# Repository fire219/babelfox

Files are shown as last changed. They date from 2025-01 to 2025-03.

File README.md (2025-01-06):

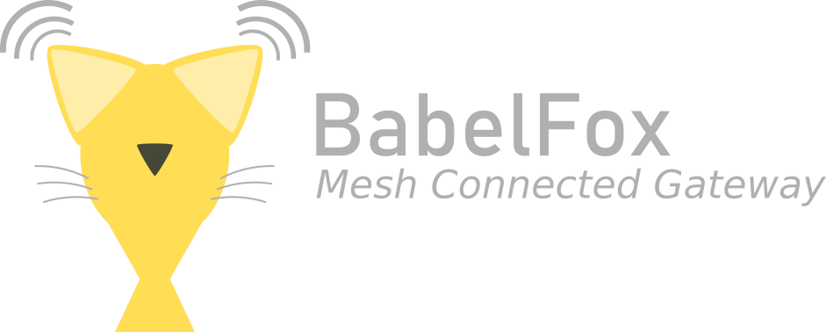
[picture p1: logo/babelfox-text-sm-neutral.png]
BabelFox logo

**NOTE: This project is not quite ready for prime time. Everything could be subject to change; build at your own risk. More documentation will come on full release.**

## What is this?
**BabelFox** is a project to create an energy efficient yet high performance Meshtastic "remote gateway node" -- one which not only has a wide TX/RX range on the mesh, but also can bridge the gap to other communication protocols, *without the need for any additional equipment*. It is equipped with a LoRA module based on the **Semtech LR1121** chip, which not only provides better RX performance than the standard SX1262 used by most Meshtastic hardware, but also includes 2.4GHz LoRA capability. It is also equipped with a **SIMCom SIM7022** LTE modem, which provides low power NB-IoT internet connectivity, with global cellular band support.

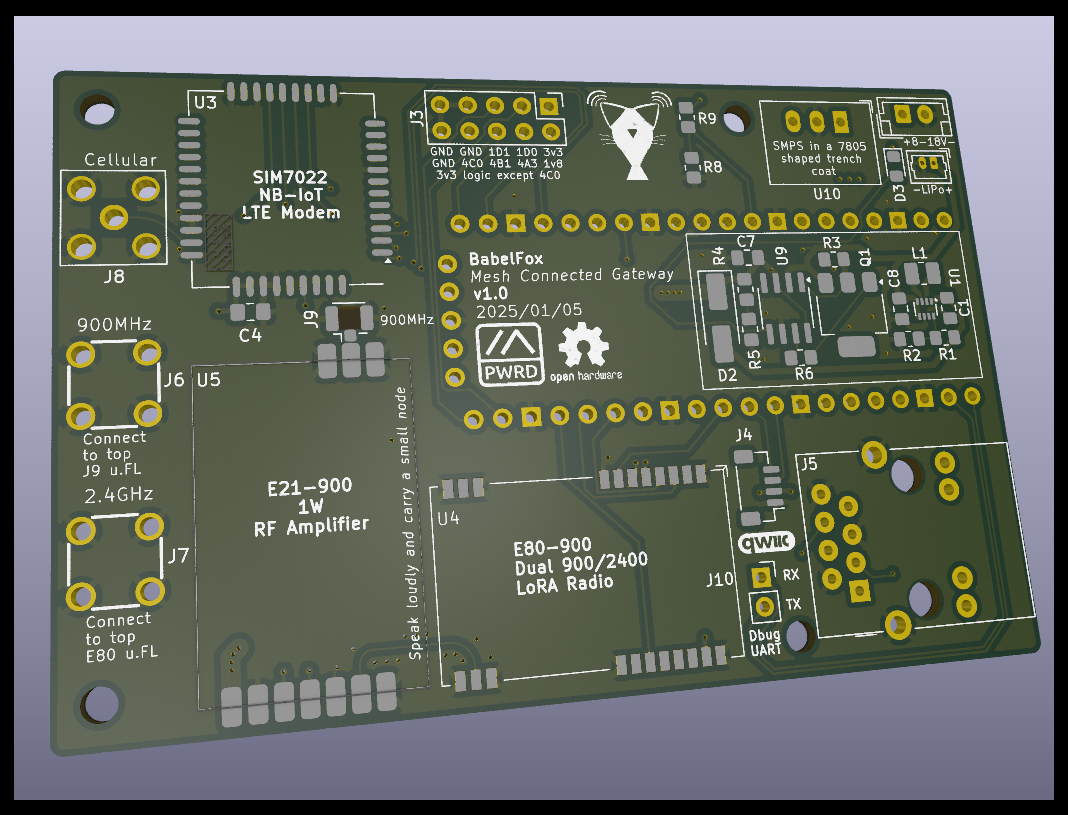
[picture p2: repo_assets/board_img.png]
BabelFox board view


## Specifications
**Form factor:** RPi compatible (85x56mm, with 58x49mm spaced mounting holes)

**Main Processor:** Luckfox Pico (based on Rockchip RV1103)

**LoRA Radio:** EByte E80-900 (based on Semtech LR1121)

**900MHz Amplifier:** EByte E21-900 1W PA/LNA

**Cell Radio:** SIMCom SIM7022

**Max LoRA TX Power:** 30dBm @ 900MHz, 13dBm @ 2.4GHz

**Power Source:** USB-C (5V only), 3.7V LiPo, 8-18V VDC

**Power Consumption:** ~5W peak, <3W nominal

## License

**BabelFox** is licensed under the CERN OHL v2 Strongly Reciprocal license. See the *LICENSE* file for more information.

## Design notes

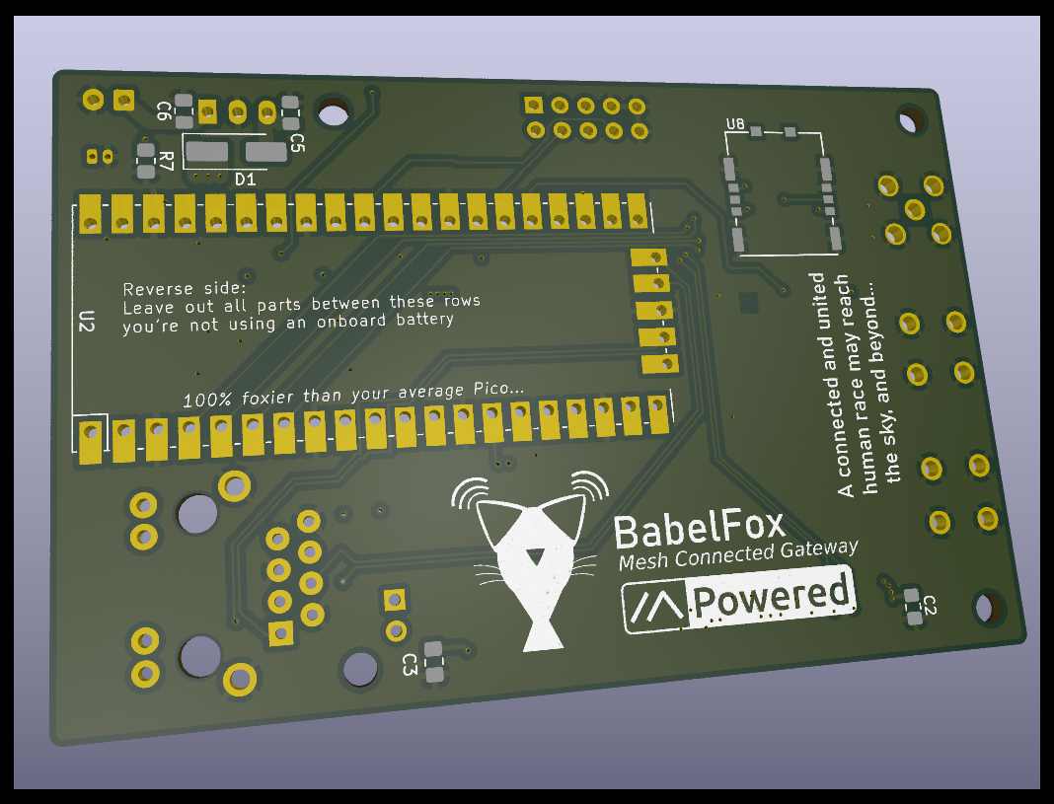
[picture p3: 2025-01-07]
repo_assets/board_img2.png

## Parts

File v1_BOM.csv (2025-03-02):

Reference | Value | Footprint | Qty | Notes
C1 | 100uF | Capacitor_SMD:C_0805_2012Metric_Pad1.18x1.45mm_HandSolder | 1 | 6V, DNP if no battery circuit
C2,C3,C4,C5,C6,C8 | 10uF | Capacitor_SMD:C_0805_2012Metric_Pad1.18x1.45mm_HandSolder | 6 | 25V, qty 5 if no battery circuit
C7 | 0.1uF | Capacitor_SMD:C_0805_2012Metric_Pad1.18x1.45mm_HandSolder | 1 | DNP if no battery circuit
D1,D2 | 30V DO-214 | Diode_SMD:D_SMA_Handsoldering | 2 | 30V
D3 | red | LED_SMD:LED_0805_2012Metric_Pad1.15x1.40mm_HandSolder | 1
J1 | DCIN | Connector_JST:JST_EH_B2B-EH-A_1x02_P2.50mm_Vertical | 1
J2 | Battery | Connector_Molex:Molex_PicoBlade_53047-0210_1x02_P1.25mm_Vertical | 1 | DNP if no battery circuit
J3 | GPIO | Connector_PinHeader_2.54mm:PinHeader_2x05_P2.54mm_Vertical | 1
J4 | Qwiic | Connector_JST:JST_SH_BM04B-SRSS-TB_1x04-1MP_P1.00mm_Vertical | 1
J5 | RJ45_Bel_SI-60062-F | Connector_RJ:RJ45_Bel_SI-60062-F | 1
J6 | LoRA 900 SMA | SMA-uFL jack:SMA-TH_2LC15SF025 | 1 | SMA with pre-wired u.FL/IPEX pigtail
J7 | LoRA 2.4G ANT | SMA-uFL jack:SMA-TH_2LC15SF025 | 1 | SMA with pre-wired u.FL/IPEX pigtail
J8 | Cellular Ant | Connector_Coaxial:SMA_Amphenol_132203-12_Horizontal | 1
J9 | LoRA 900 u.FL | Connector_Coaxial:U.FL_Hirose_U.FL-R-SMT-1_Vertical | 1
J10 | Debug UART | Connector_PinSocket_2.54mm:PinSocket_1x02_P2.54mm_Vertical | 1
L1 | 1uH | Inductor_SMD:L_1008_2520Metric_Pad1.43x2.20mm_HandSolder | 1 | Isat > 3A, DNP if no battery circuit
Q1 | FZ788B | Package_TO_SOT_SMD:SOT-223 | 1 | DNP if no battery circuit
R1 | 806 | Resistor_SMD:R_0805_2012Metric_Pad1.20x1.40mm_HandSolder | 1 | DNP if no battery circuit
R2 | 91 | Resistor_SMD:R_0805_2012Metric_Pad1.20x1.40mm_HandSolder | 1 | DNP if no battery circuit
R3 | 0.2 | Resistor_SMD:R_0805_2012Metric_Pad1.20x1.40mm_HandSolder | 1 | DNP if no battery circuit
R4,R5,R6 | 1k | Resistor_SMD:R_0805_2012Metric_Pad1.20x1.40mm_HandSolder | 3 | DNP if no battery circuit
R7 | 2k | Resistor_SMD:R_0805_2012Metric_Pad1.20x1.40mm_HandSolder | 1 | DNP if no battery circuit
R8 | 100k 1% | Resistor_SMD:R_0805_2012Metric_Pad1.20x1.40mm_HandSolder | 1 | DNP if no battery circuit
R9 | 150k 1% | Resistor_SMD:R_0805_2012Metric_Pad1.20x1.40mm_HandSolder | 1 | DNP if no battery circuit
U1 | TPS631000 | Package_TO_SOT_SMD:SOT-583-8 | 1 | DNP if no battery circuit
U2 | LuckFox_Pico | LuckFox_Pico:LuckFox_Pico | 1
U3 | SIM7022 | SIM7022:SIMCom_SIM7022 | 1
U4 | E80-900M2213S | E80-x00M2213S:E80-x00M2213S | 1
U5 | E21-900G30S | E21-x00G30S:E21-x00G30S | 1
U8 | NanoSIM Slot | simcard:1042240820_MOL | 1
U9 | BQ2057CSNTR | Package_SO:SOIC-8_3.9x4.9mm_P1.27mm | 1 | DNP if no battery circuit
U10 | "7805" drop-in SMPS | Converter_DCDC:Converter_DCDC_RECOM_R-78E-0.5_THT | 1 | >1.5A output recommended

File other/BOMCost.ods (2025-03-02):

BabelFox BOMCost
Part | Qty per bd | Qty1 $ | BQty1 $ | Qty10 $ | BQty10 $ | Source
Luckfox Pico | 1 | $7.00 | $7.00 | $70.00 | $70.00 | Luckfox | No Battery Circuit
E80-900 | 1 | $6.69 | $6.69 | $66.90 | $66.90 | AliEx | Board Cost @ Qty1 | $39.54
E21-900 | 1 | $3.99 | $3.99 | $39.99 | $39.99 | AliEx | Board Cost @ Qty10 | $37.26
SIM7022 | 1 | $5.00 | $5.00 | $50.00 | $50.00 | AliEx
“7805” 1.5A SMPS | 1 | $4.87 | $4.87 | $44.71 | $44.71 | DigiKey | Complete Board
10uF 0805 cap | 3 | $0.11 | $0.33 | $0.37 | $1.11 | DigiKey | Board Cost @ Qty1 | $49.06
power diode | 1 | $0.44 | $0.44 | $3.66 | $3.66 | DigiKey | Board Cost @ Qty10 | $43.78
DC-in JST-EH | 1 | $0.10 | $0.10 | $0.76 | $0.76 | DigiKey
GPIO header | 1 | $0.44 | $0.44 | $3.57 | $3.57 | DigiKey | (ignoring PCB cost)
Qwiic conn | 1 | $0.54 | $0.54 | $4.43 | $4.43 | DigiKey
RJ45 magjack | 1 | $4.90 | $4.90 | $39.93 | $39.93 | DigiKey
Cell SMA | 1 | $2.85 | $2.85 | $23.84 | $23.84 | DigiKey
LoRA SMA-uFL | 2 | $1.05 | $2.10 | $10.54 | $21.08 | AliEx
LoRA uFL | 1 | $0.19 | $0.19 | $1.90 | $1.90 | DigiKey
debug UART header | 1 | $0.10 | $0.10 | $0.76 | $0.76 | DigiKey
Battery Circuit:
BQ2057 (bt chgr) | 1 | $3.14 | $3.14 | $23.53 | $23.53 | DigiKey
TPS631000 (bt reg) | 1 | $1.42 | $1.42 | $10.46 | $10.46 | DigiKey
100uF 0805 cap | 1 | $1.09 | $1.09 | $6.73 | $6.73 | DigiKey
10uF 0805 cap | 3 | $0.11 | $0.33 | $0.37 | $1.11 | DigiKey
0.1uF 0805 cap | 1 | $0.10 | $0.10 | $0.47 | $0.47 | DigiKey
power diode | 1 | $0.44 | $0.44 | $3.66 | $3.66 | DigiKey
charge LED | 1 | $0.17 | $0.17 | $1.70 | $1.70 | DigiKey
battery picoblade | 1 | $0.17 | $0.17 | $1.39 | $1.39 | DigiKey
1uH inductor | 1 | $0.28 | $0.28 | $2.15 | $2.15 | DigiKey
FZT788 chg trans | 1 | $1.35 | $1.35 | $8.53 | $8.53 | DigiKey
806ohm 0.1% 0805 | 1 | $0.14 | $0.14 | $1.01 | $1.01 | DigiKey
91ohm 0.1% 0805 | 1 | $0.14 | $0.14 | $1.01 | $1.01 | DigiKey
0.2ohm 1% 0805 | 1 | $0.17 | $0.17 | $0.86 | $0.86 | DigiKey
1kohm 1% 0805 | 2 | $0.10 | $0.20 | $0.16 | $0.32 | DigiKey
2kohm 1% 0805 | 1 | $0.10 | $0.10 | $0.16 | $0.16 | DigiKey
100k 0.1% 0805 | 1 | $0.14 | $0.14 | $1.01 | $1.01 | DigiKey
150k 0.1% 0805 | 1 | $0.14 | $0.14 | $1.01 | $1.01 | DigiKey

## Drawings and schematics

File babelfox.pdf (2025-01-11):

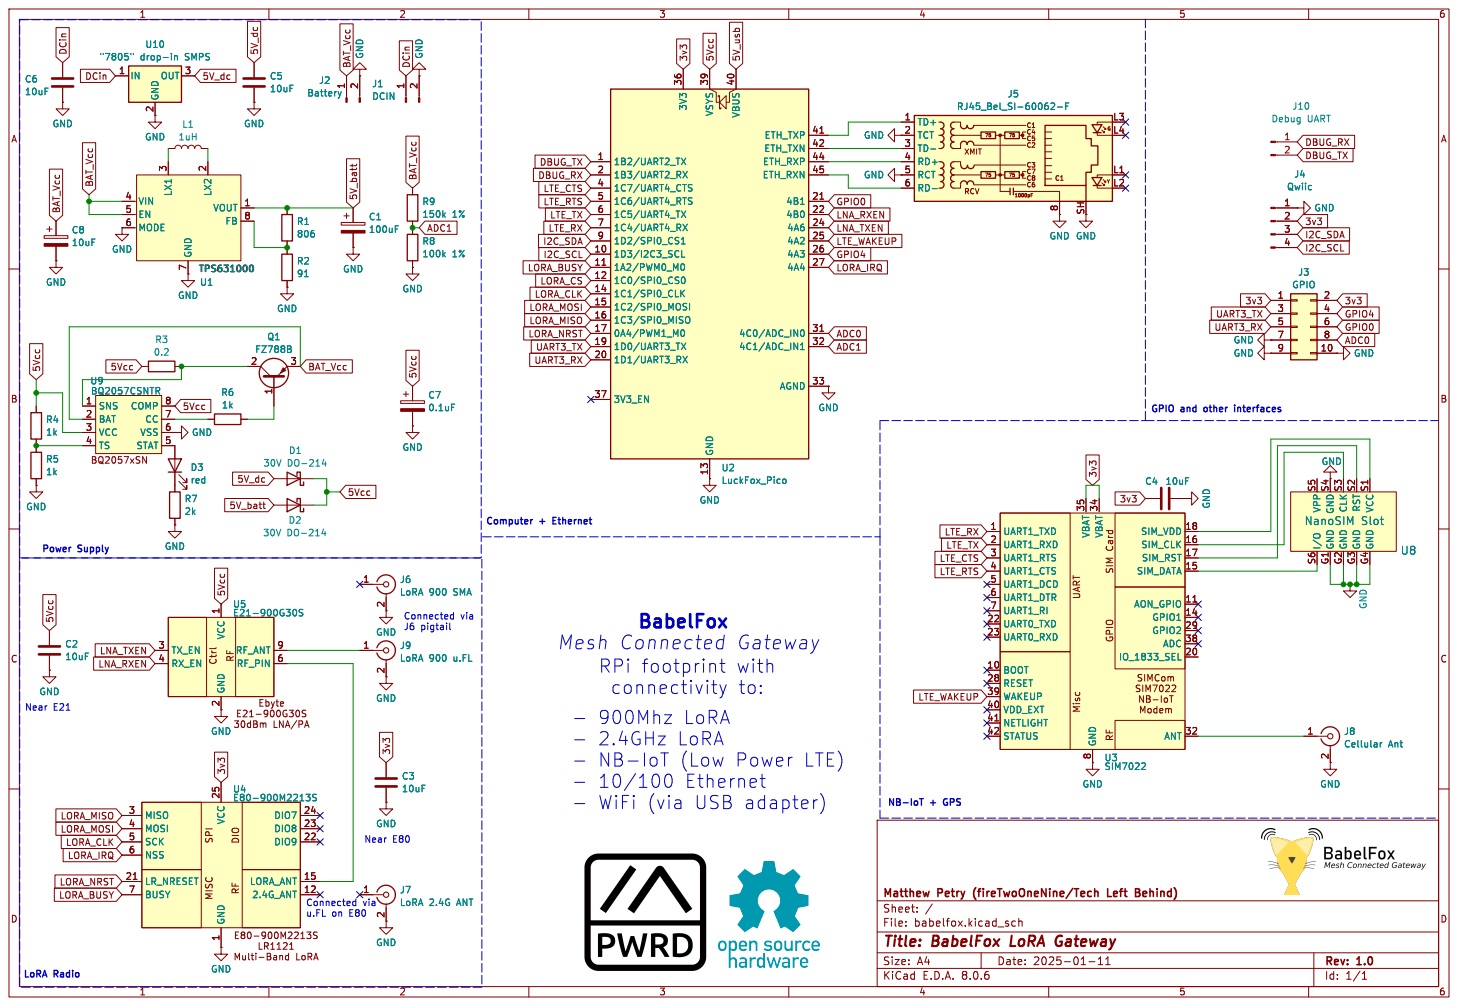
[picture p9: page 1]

TD+ 1 TCT 2 TD- 3 RD+ 4 RCT 5 RD- 6

Y TD+ 1 TCT 2 TD- 3 RD+ 4 RCT 5 RD- 6

4 GND GND GND GND

3 VIN 4 EN 5 MODE 6 GND

- 2.4GHz LoRA
- NB-IoT (Low Power LTE)

Id: 1/1 Title: BabelFox LoRA Gateway

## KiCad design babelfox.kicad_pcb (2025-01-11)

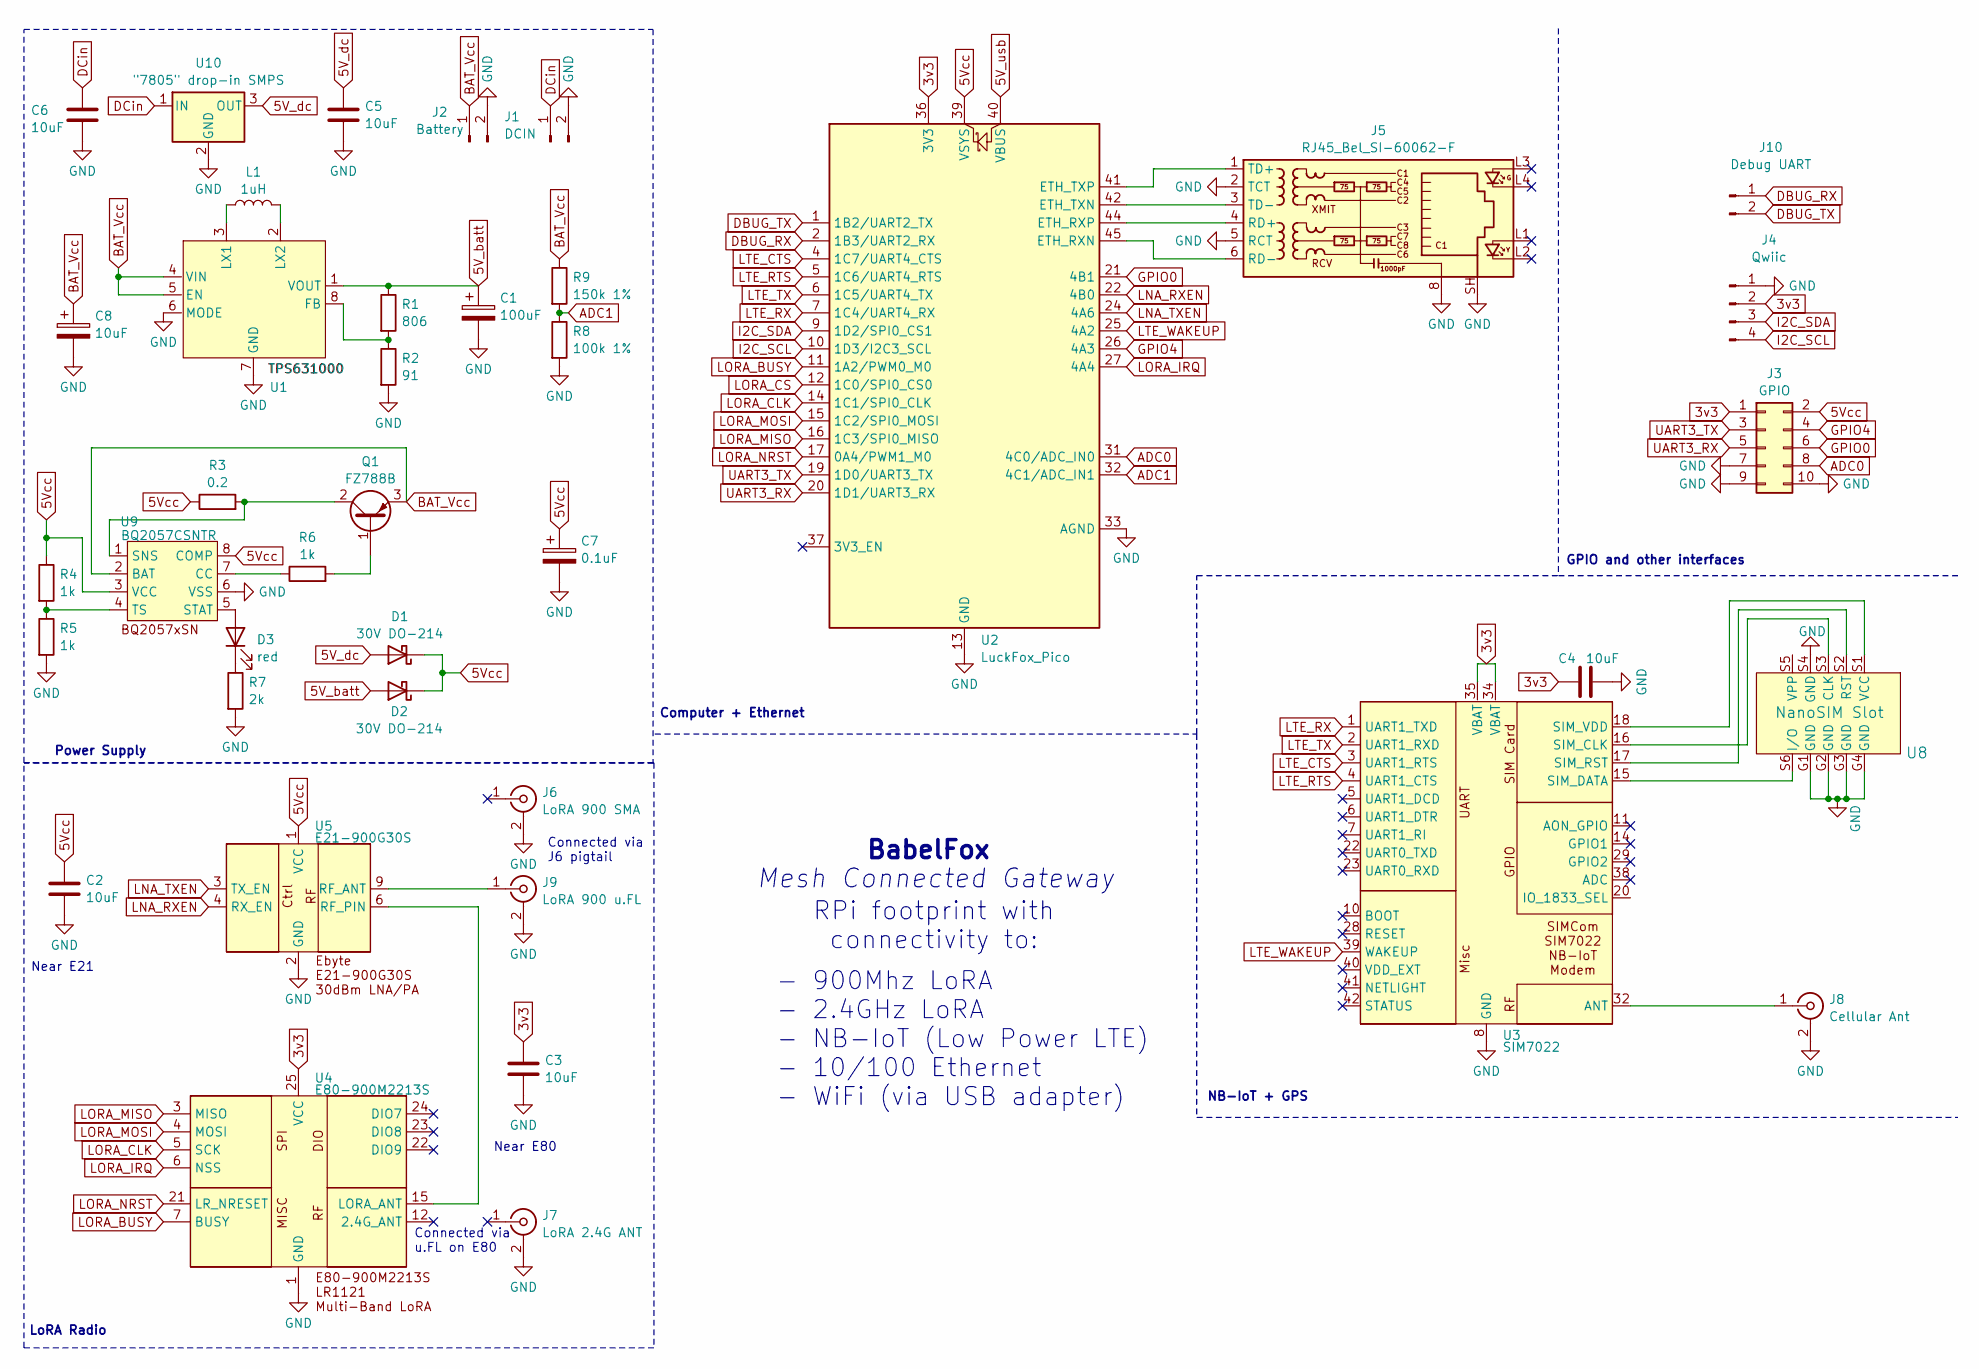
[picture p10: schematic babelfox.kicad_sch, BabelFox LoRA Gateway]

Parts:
C1: 100uF; C_0805_2012Metric_Pad1.18x1.45mm_HandSolder; LCSC C141660
C2, C3, C4, C5, C6, C8: 10uF; C_0805_2012Metric_Pad1.18x1.45mm_HandSolder; LCSC C15850
C7: 0.1uF; C_0805_2012Metric_Pad1.18x1.45mm_HandSolder; LCSC C17604
D1, D2: 30V DO-214; D_SMA_Handsoldering; LCSC C511853
D3: red; LED_0805_2012Metric_Pad1.15x1.40mm_HandSolder; LCSC C5156920
J1: DCIN; JST_EH_B2B-EH-A_1x02_P2.50mm_Vertical
J2: Battery; Molex_PicoBlade_53047-0210_1x02_P1.25mm_Vertical
J3: GPIO; PinHeader_2x05_P2.54mm_Vertical
J4: Qwiic; JST_SH_BM04B-SRSS-TB_1x04-1MP_P1.00mm_Vertical
J5: RJ45_Bel_SI-60062-F
J6: LoRA 900 SMA; SMA-TH_2LC15SF025
J7: LoRA 2.4G ANT; SMA-TH_2LC15SF025
J8: Cellular Ant; SMA_Amphenol_132203-12_Horizontal
J9: LoRA 900 u.FL; U.FL_Hirose_U.FL-R-SMT-1_Vertical; LCSC C88373
J10: Debug UART; PinSocket_1x02_P2.54mm_Vertical
L1: 1uH; L_1008_2520Metric_Pad1.43x2.20mm_HandSolder; LCSC C76827
Q1: FZ788B; SOT-223; LCSC C141330
R1: 806; R_0805_2012Metric_Pad1.20x1.40mm_HandSolder; LCSC C2999620
R2: 91; R_0805_2012Metric_Pad1.20x1.40mm_HandSolder; LCSC C4407
R3: 0.2; R_0805_2012Metric_Pad1.20x1.40mm_HandSolder; LCSC C44051
R4, R5, R6: 1k; R_0805_2012Metric_Pad1.20x1.40mm_HandSolder; LCSC C17513
R7: 2k; R_0805_2012Metric_Pad1.20x1.40mm_HandSolder
R8: 100k 1%; R_0805_2012Metric_Pad1.20x1.40mm_HandSolder; LCSC C25611
R9: 150k 1%; R_0805_2012Metric_Pad1.20x1.40mm_HandSolder; LCSC C17470
U1: TPS631000; SOT-583-8; LCSC C5219190
U2: LuckFox_Pico
U3: SIM7022; SIMCom_SIM7022
U4: E80-900M2213S; E80-x00M2213S
U5: E21-900G30S; E21-x00G30S
U8: NanoSIM Slot; 1042240820_MOL; LCSC C585349
U9: BQ2057CSNTR; SOIC-8_3.9x4.9mm_P1.27mm; LCSC C2866550
U10: "7805" drop-in SMPS; Converter_DCDC_RECOM_R-78E-0.5_THT

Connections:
3v3: C3.1, C4.1, J3.1, J4.2, U2.36 (3V3), U3.34 (VBAT), U3.35 (VBAT), U4.25 (VCC)
5V_batt: C1.1, D2.2 (A), R1.1, U1.1 (VOUT)
5V_dc: C5.1, D1.2 (A), U10.3 (OUT)
5V_usb: U2.40 (VBUS)
5Vcc: C2.1, C7.1, D1.1 (K), D2.1 (K), J3.2, R3.1, R4.1, U2.39 (VSYS), U5.1 (VCC), U9.3 (VCC), U9.8 (COMP)
ADC0: J3.8, U2.31 (4C0/ADC_IN0)
ADC1: R8.1, R9.2, U2.32 (4C1/ADC_IN1)
BAT_Vcc: C8.1, J2.1, Q1.3 (E), R9.1, U1.4 (VIN), U1.5 (EN), U9.2 (BAT)
DBUG_RX: J10.1, U2.2 (1B3/UART2_RX)
DBUG_TX: J10.2, U2.1 (1B2/UART2_TX)
DCin: C6.1, J1.1, U10.1 (IN)
GND: C1.2, C2.2, C3.2, C4.2, C5.2, C6.2, C7.2, C8.2, J1.2, J2.2, J3.7, J3.9, J3.10, J4.1, J5.2 (TCT), J5.5 (RCT), J5.8, J5.SH, J6.2 (Ext), J7.2 (Ext), J8.2 (Ext), J9.2 (Ext), R2.2, R5.2, R7.2, R8.2, U1.6 (MODE), U1.7 (GND), U2.3 (GND), U2.8 (GND), U2.13 (GND), U2.18 (GND), U2.23 (GND), U2.28 (GND), U2.33 (AGND), U2.38 (GND), U2.43 (GND), U3.8 (GND), U3.13 (GND), U3.19 (GND), U3.21 (GND), U3.27 (GND), U3.30 (GND), U3.31 (GND), U3.33 (GND), U3.36 (GND), U3.37 (GND), U4.1 (GND), U4.8 (GND), U4.11 (GND), U4.13 (GND), U4.14 (GND), U4.16 (GND), U4.19 (GND), U4.26 (GND), U5.2 (GND), U5.5 (GND), U5.7 (GND), U5.8 (GND), U5.10 (GND), U8.G1 (GND), U8.G2 (GND), U8.G3 (GND), U8.G4 (GND), U8.S4 (GND), U9.6 (VSS), U10.2 (GND)
GPIO0: J3.6, U2.21 (4B1)
GPIO4: J3.4, U2.26 (4A3)
I2C_SCL: J4.4, U2.10 (1D3/I2C3_SCL)
I2C_SDA: J4.3, U2.9 (1D2/SPI0_CS1)
LNA_RXEN: U2.22 (4B0), U5.4 (RX_EN)
LNA_TXEN: U2.24 (4A6), U5.3 (TX_EN)
LORA_BUSY: U2.11 (1A2/PWM0_M0), U4.7 (BUSY)
LORA_CLK: U2.14 (1C1/SPI0_CLK), U4.5 (SCK)
LORA_CS: U2.12 (1C0/SPI0_CS0)
LORA_IRQ: U2.27 (4A4), U4.6 (NSS)
LORA_MISO: U2.16 (1C3/SPI0_MISO), U4.3 (MISO)
LORA_MOSI: U2.15 (1C2/SPI0_MOSI), U4.4 (MOSI)
LORA_NRST: U2.17 (0A4/PWM1_M0), U4.21 (LR_NRESET)
LTE_CTS: U2.4 (1C7/UART4_CTS), U3.3 (UART1_RTS)
LTE_RTS: U2.5 (1C6/UART4_RTS), U3.4 (UART1_CTS)
LTE_RX: U2.7 (1C4/UART4_RX), U3.1 (UART1_TXD)
LTE_TX: U2.6 (1C5/UART4_TX), U3.2 (UART1_RXD)
LTE_WAKEUP: U2.25 (4A2), U3.39 (WAKEUP)
unnamed: D3.2 (A), U9.5 (STAT)
unnamed: D3.1 (K), R7.1
unnamed: J5.4 (RD+), U2.44 (ETH_RXP)
unnamed: J5.6 (RD-), U2.45 (ETH_RXN)
unnamed: J5.1 (TD+), U2.41 (ETH_TXP)
unnamed: J5.3 (TD-), U2.42 (ETH_TXN)
unnamed: J8.1 (In), U3.32 (ANT)
unnamed: J9.1 (In), U5.9 (RF_ANT)
unnamed: Q1.1 (B), R6.2
unnamed: Q1.2 (C), R3.2, U9.1 (SNS)
unnamed: R1.2, R2.1, U1.8 (FB)
unnamed: L1.1, U1.3 (LX1)
unnamed: L1.2, U1.2 (LX2)
unnamed: U3.16 (SIM_CLK), U8.S3 (CLK)
unnamed: U3.15 (SIM_DATA), U8.S6 (I/O)
unnamed: U3.17 (SIM_RST), U8.S2 (RST)
unnamed: U3.18 (SIM_VDD), U8.S1 (VCC)
unnamed: U4.15 (LORA_ANT), U5.6 (RF_PIN)
unnamed: R6.1, U9.7 (CC)
unnamed: R4.2, R5.1, U9.4 (TS)
UART3_RX: J3.5, U2.20 (1D1/UART3_RX)
UART3_TX: J3.3, U2.19 (1D0/UART3_TX)

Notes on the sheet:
Connected via J6 pigtail
Near E21
RPi footprint with connectivity to:
NB-IoT + GPS
Mesh Connected Gateway
Computer + Ethernet
Power Supply
Near E80
LoRA Radio
Connected via u.FL on E80
BabelFox
- 900Mhz LoRA - 2.4GHz LoRA - NB-IoT (Low Power LTE) - 10/100 Ethernet - WiFi (via USB adapter)
GPIO and other interfaces

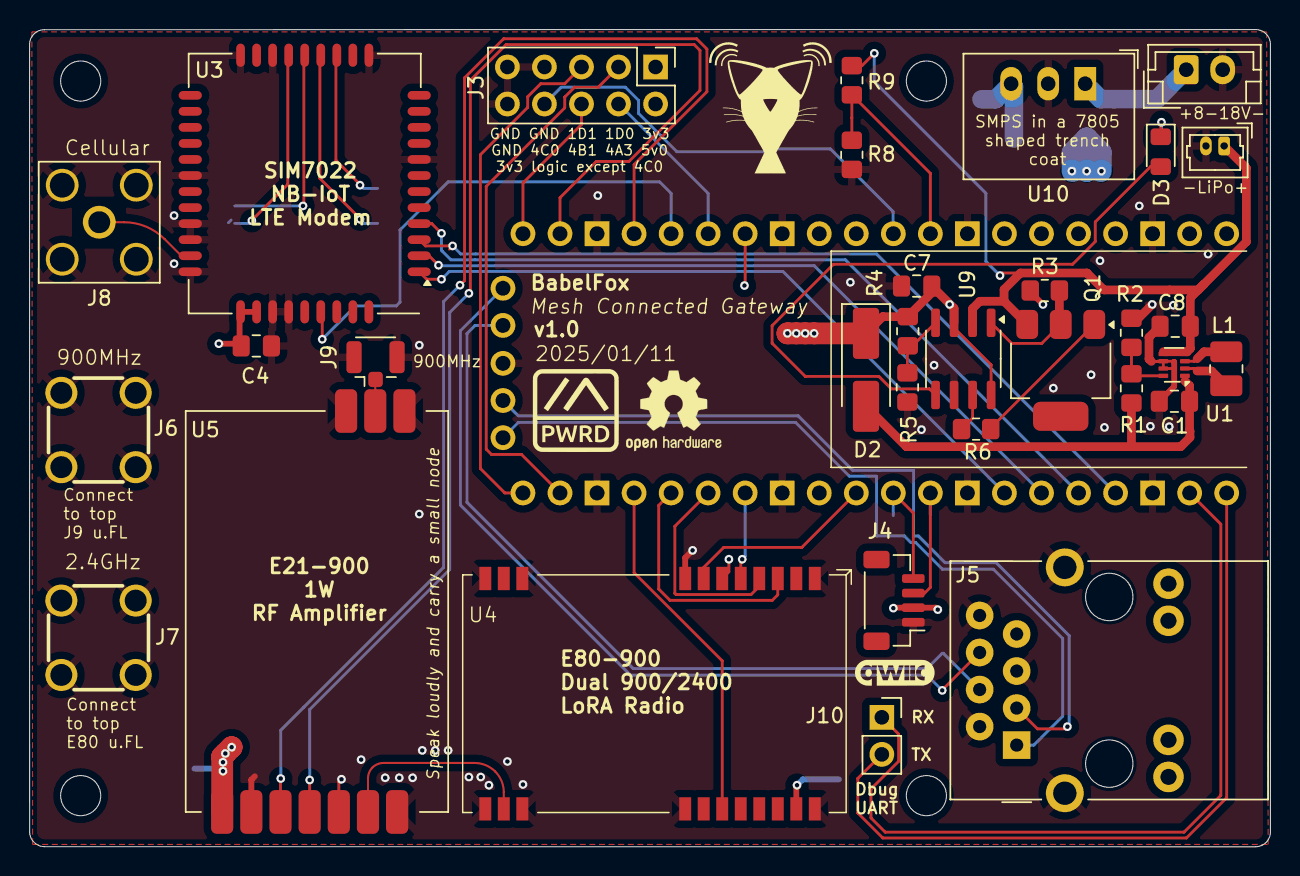
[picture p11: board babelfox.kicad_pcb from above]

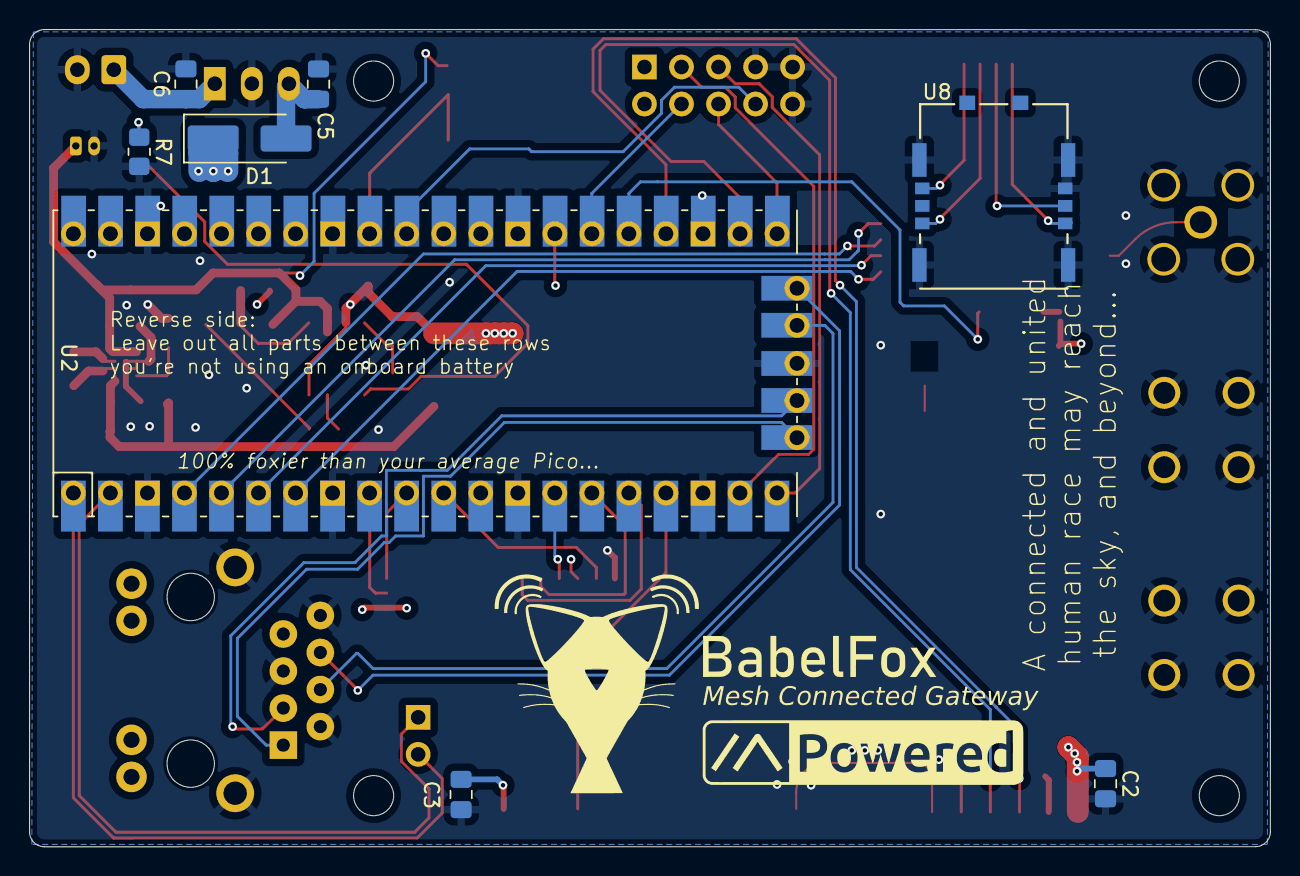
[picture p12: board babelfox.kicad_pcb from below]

Board: 4 copper layers, 85.1 x 56.0 mm, 43 parts (10 on the bottom side), 50 nets.

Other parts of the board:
.: LOGO; babelfox_logo_9x9
.#2: LOGO; m_powered2
.#3: LOGO; babelfox_logo

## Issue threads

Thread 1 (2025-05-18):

LoRa radio miswired and other issues with PCB v1.0

porkcube, 2025-05-18:
Hello!   I was able to get a v1.0 PCB working, with the `SIM 7022` LTE Modem (at least it's responding to AT commands) easily, but not so much the `E80-900M2213S` as it's wired up incorrectly.

`LORA_IRQ` should be going to `DIO9` on the E80, and `LORA_CS` should go to `CS` on the E80 instead of left unconnected.

There's also seems to be issues with your choice of pins I haven't quite been able to fully work around, quite likely related in-part to using Foxbuntu as my boot image, where they use pin11/GPIO34/1A2 for the Activity LED as the Luckfox Pico Mini A/B have a second LED the Luckfox Pico lacks, and is possibly something related to custom dtd/dts.  In the end I jumpered `LORA_IRQ` to pin19/GPIO56/1D0, and `LORA_BUSY` to pin20/GPIO7/1D1 and set `UART3_M1_STATUS=0` in `/etc/luckfox.cfg` then after a reboot and many frustrating attempts finally was able to have the LoRa radio operational.

Ethernet however I have yet to get back to but I was unable to get it working initially and even having the jack soldered was causing issues with my usual hack job of just soldering a chopped ethernet cable to the Tx/Rx pins so removed it.  It might be worth switching to the Hanrun `HR911105A` the Femtofox PCB uses as it's a cheaper part and known working wiring to crib from (the datasheets just listing pin 1 and 8 but not the others is quite confusing from what I've seen).

Additionally the battery charging circuit may not be operating correctly.  When powered off just a LiPo battery it appeared to boot up but then quickly browned out.  I then applied 9.5V from bench supply and watchied it flipping between powering the Babelfox for ~.5s, then not, then on, then not as it seemed to be swapping between running off the 9.5V and the battery.  That could certainly be something from my improvised BOM or assembly, and something I need to go back and reflow / ohm everything out then try with a serial connection running before I'd say more certainly it's not my own fault.

Just wanted to let ya know someone's actually built one, well two actually, and here's [a working meshtasticd config](https://gist.github.com/porkcube/f845dcb3d4e902e2cfe44bdd1c5e659e) for the above modifications.

porkcube, 2025-05-18:
Got Ethernet working, problems there are pins 2 & 5 being tied to GROUND instead of left floating, and the TX/RX need to be crossed so Luckfox TX +/- <-> SI-60062 RX +/- & Luckfox RX +/- <-> SI-60062 TX +/-.

Additionally haven't been able to get the LTE Modem talking with a SIM card, most example circuits I've seen match Simcomm's example circuit with 22Ω resistors inline for CLOCK/RESET/DATA and Simcomm's own example also having 33pƒ cap before the resistors to ground on the same lines so chalking it up to noisy signal until I have time to further hack up a v1.0 PCB and try the resistor and caps.

porkcube, 2025-05-19:
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

This is the wiring for the `E80-900M2213S` that's working for me

porkcube, 2025-06-02:
Have the SIM working too so the circuit there seems fine, what tends to happen if there's something off with the socket connection is `CME ERROR: 10` (aka "SIM not inserted") returned by the **SIM 7022** trying to access it.  If there's connection issues and the SIM was inserted at boot the modem may appear "dead" and unresponsive to `AT` commands.

If the SIM connections are good and the SIM is hotswapped / inserted post boot I've still had some issues with it but had been to reliably use `AT+QCRST` to reset the **SIM 7022** at which point it then correctly detects the SIM and can access it.

I've [documented some other useful commands](https://gist.github.com/porkcube/706e8eb6e82a9d2c2b3d09bf61d774f5) as well.

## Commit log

2025-01-01 prerelease, may contain dragons
    [babelfox.kicad_pcb, babelfox.kicad_sch]
2025-01-02 board cleanup, add images
    [babelfox.kicad_pcb]
2025-01-02 neutral color logo for light/dark mode github compat
    [babelfox.kicad_pcb]
2025-01-06 Jan 5 progress, update license to OHL-S
    [babelfox.kicad_pcb, babelfox.kicad_sch]
2025-01-07 LCSC IDs; OSHW silkscreen; new imgs
    [babelfox.kicad_sch]
2025-01-08 LCSC inductor... but i'm not doing LCSC anymore
    [babelfox.kicad_pcb, babelfox.kicad_sch]
2025-01-11 board as sent to JLC 1/11
    [babelfox-B_Cu.gbr, babelfox-B_Mask.gbr, babelfox-B_Paste.gbr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]
2025-03-02 push BOM
    [BOMCost.ods, babelfox.kicad_sch, v1_BOM.csv]
